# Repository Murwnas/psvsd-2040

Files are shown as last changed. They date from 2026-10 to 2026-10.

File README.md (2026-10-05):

# PSVSD 2040

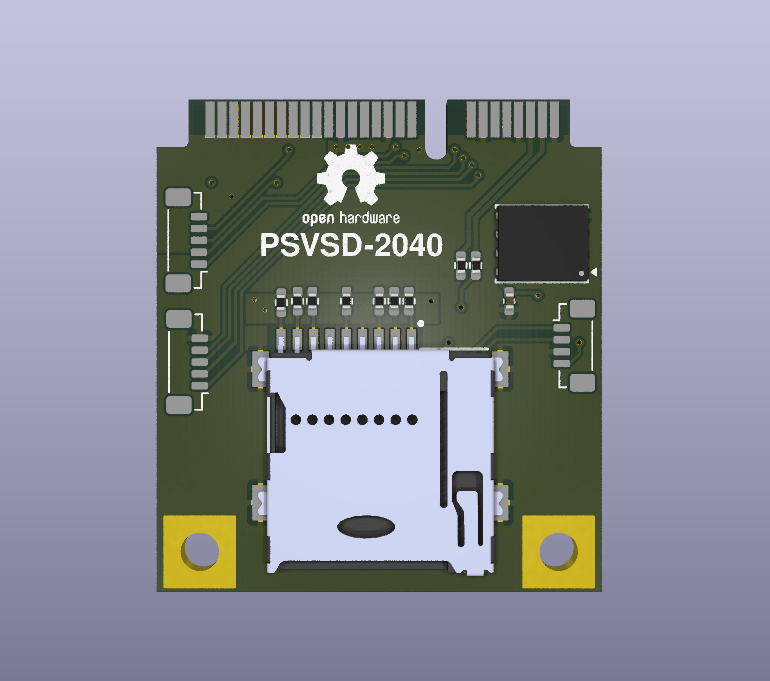
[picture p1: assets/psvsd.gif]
KiCad 3D render


This is a module based on [Yinfanlu's PSVSD adapter](https://github.com/yifanlu/psvsd/). Last year, I took the original Eagle Autodesk files and adapted them to a [KiCad EDA source](https://github.com/Murwnas/psvsd-kicad). This repo code is based on my adaptation. 

One of the problems with the original PSVSD is the out-of-production Genesys chip, which appears to be a generic USB-to-SD bridge that simply exposes Mass Storage. It's theoretically possible to use any such bridge chip in its place, but anyone who has read Yinfanlu's write-up on this will also know that power consumption is the main problem behind those adapters. The PS Vita's modem port never switches off power to the modem port. Therefore, these adapters consume power even when the console is off.

My own fun idea was to recreate this adapter using my favorite chip: The RP2040. It has a USB interface, fast GPIO lines, and very low power consumption---with the potential to go into deep-sleep-like states to draw very small amounts. 

The main downside is USB 1.1 speeds, which theoretically cap at 1.2 MB/s. 

Right now, a board has been designed and fabricated, but I have not had the time to assemble and test it. Whether this is a viable concept will remain to be seen.

Do not attempt to reproduce this unless you are fine with potentially making a faulty board that may or may not fry your PS Vita!

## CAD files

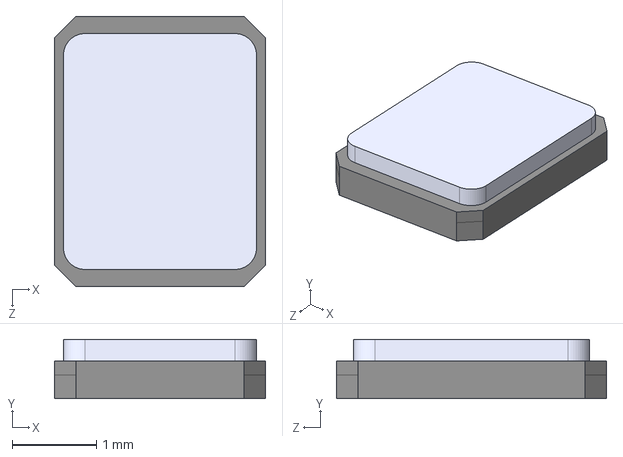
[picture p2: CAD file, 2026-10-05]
assets/step/ABM8-272-T3.STEP
2.50 x 0.7 x 3.20 mm

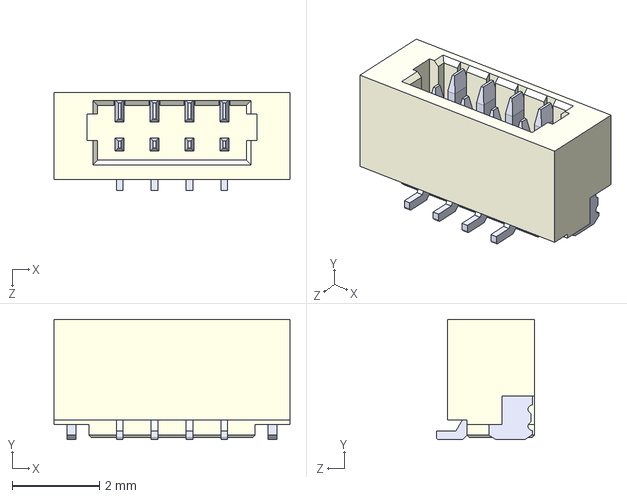
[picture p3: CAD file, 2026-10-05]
assets/step/BM04B-SURS-TF.STEP
5.40 x 2.75 x 2.25 mm

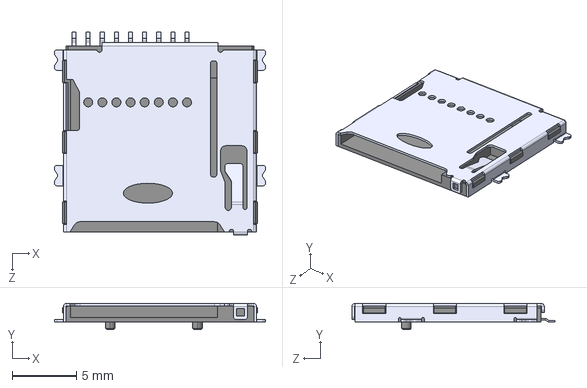
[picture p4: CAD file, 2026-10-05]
assets/step/SD_SLOT.STEP
16.4 x 2.05 x 15.9 mm

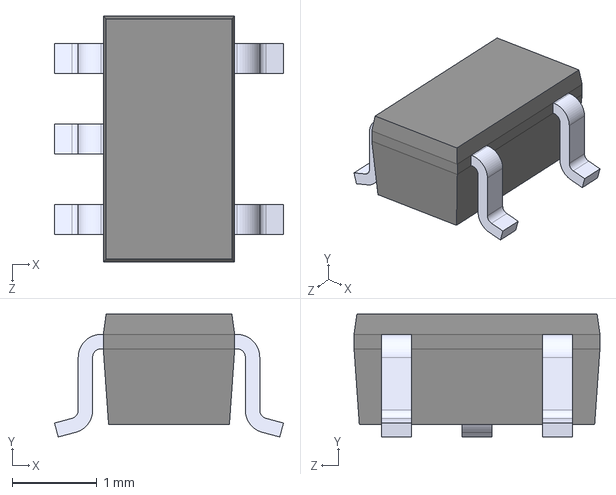
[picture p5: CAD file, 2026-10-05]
assets/step/MIC5504-3.3YM5-TR.step
2.70 x 1.45 x 2.90 mm

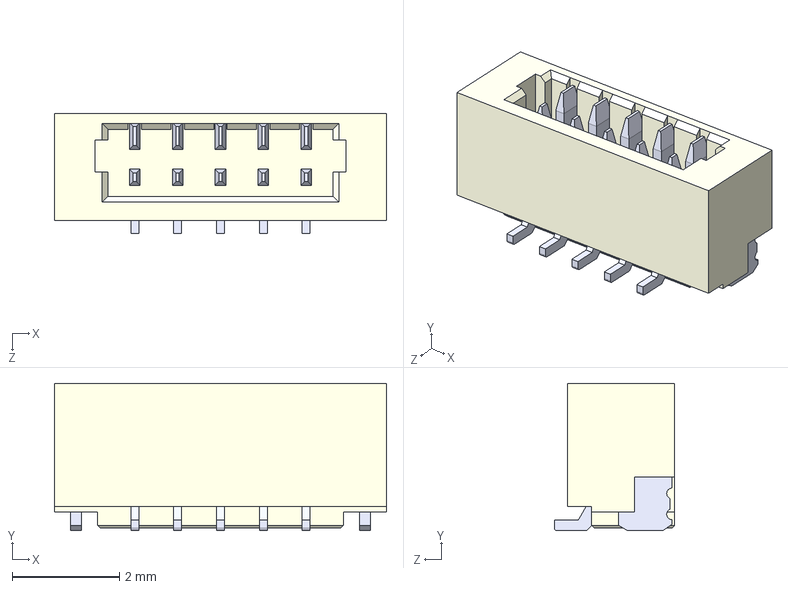
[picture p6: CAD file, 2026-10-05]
assets/step/BM05B-SURS-TF.STEP
6.20 x 2.75 x 2.25 mm

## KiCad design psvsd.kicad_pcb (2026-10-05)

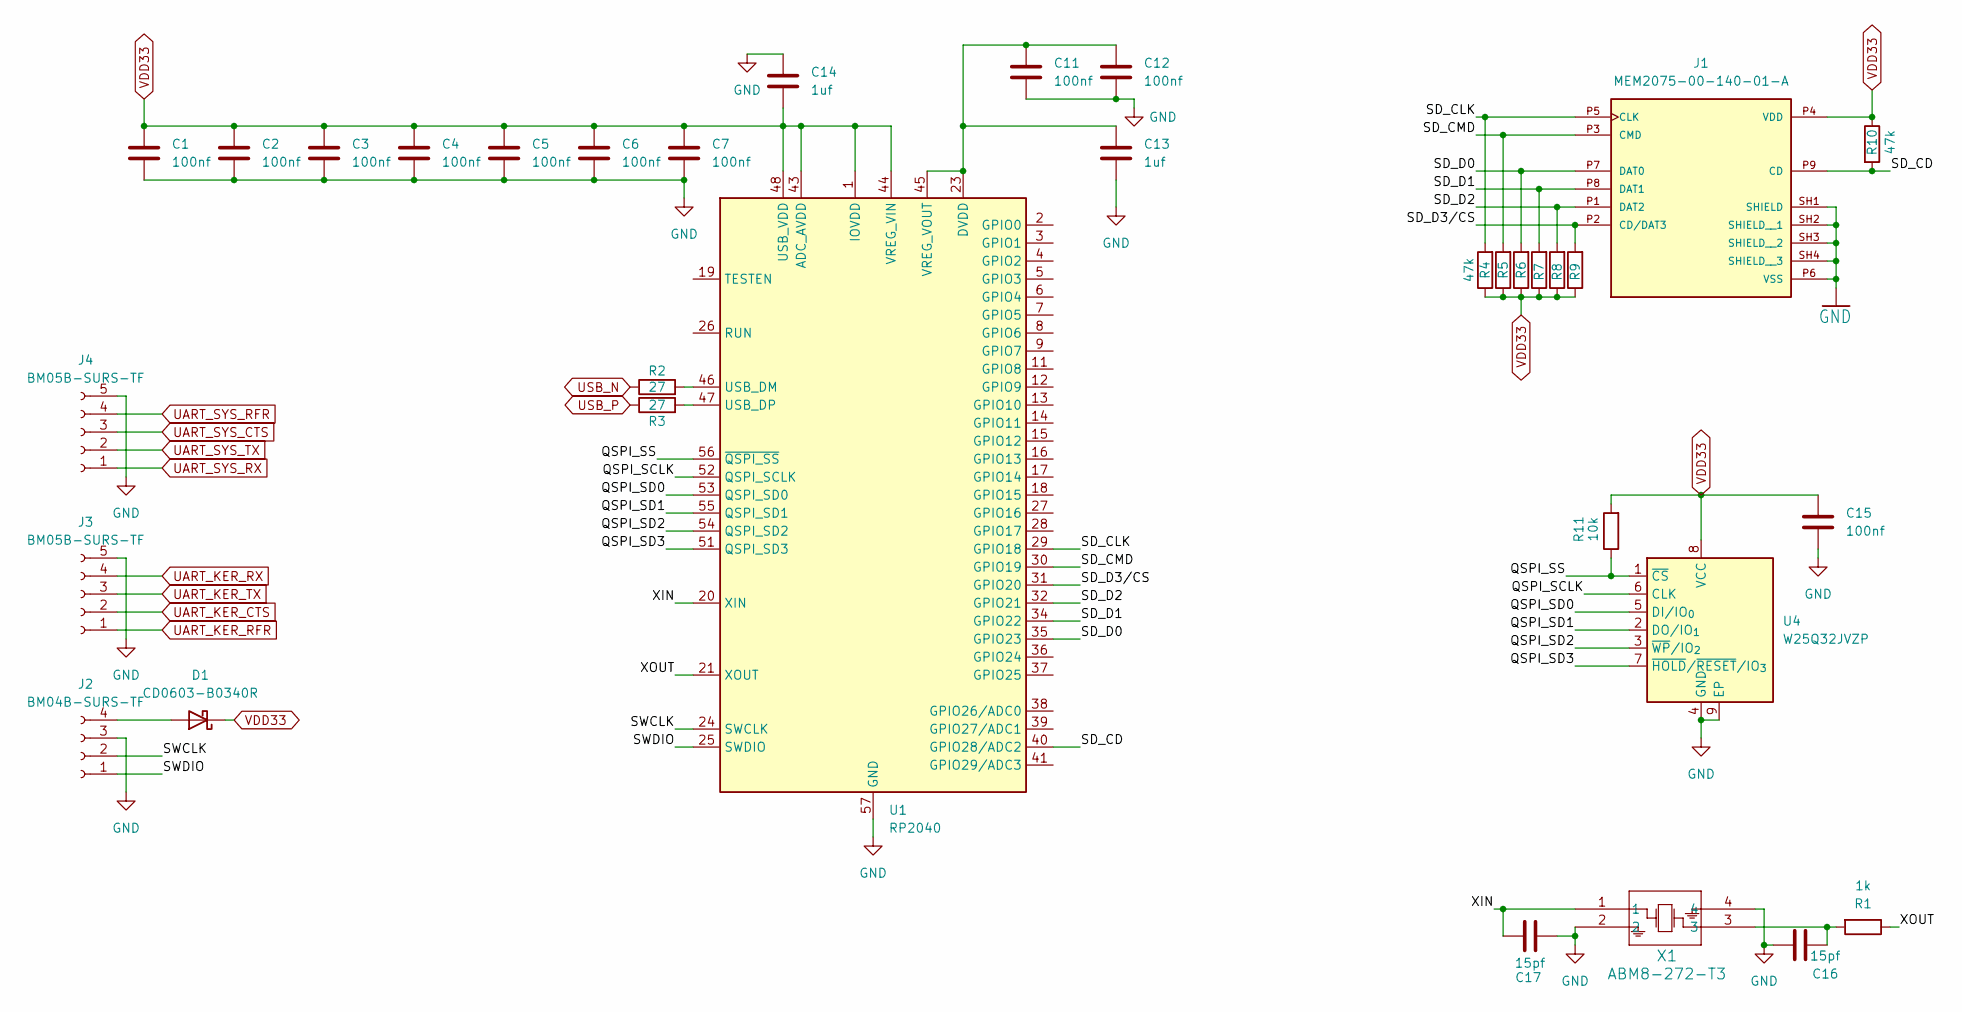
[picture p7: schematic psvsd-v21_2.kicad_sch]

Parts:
C1, C2, C3, C4, C5, C6, C7, C11, C12, C15: 100nf; C_0402_1005Metric_Pad0.74x0.62mm_HandSolder
C13, C14: 1uf; C_0402_1005Metric_Pad0.74x0.62mm_HandSolder
C16, C17: 15pf; C_0402_1005Metric_Pad0.74x0.62mm_HandSolder
D1: CD0603-B0340R; D_0603_1608Metric
J1: MEM2075-00-140-01-A; GCT_MEM2075-00-140-01-A; PARTREV A
J2: BM04B-SURS-TF; JST_SUR_BM04B-SURS-TF_1x04-1MP_P0.80mm_Vertical
J3, J4: BM05B-SURS-TF; JST_SUR_BM05B-SURS-TF_1x05-1MP_P0.80mm_Vertical
R1: 1k; R_0402_1005Metric_Pad0.72x0.64mm_HandSolder
R2, R3: 27; R_0402_1005Metric_Pad0.72x0.64mm_HandSolder
R4, R5, R6, R7, R8, R9, R10: 47k; R_0402_1005Metric_Pad0.72x0.64mm_HandSolder
R11: 10k; R_0402_1005Metric_Pad0.72x0.64mm_HandSolder
U1: RP2040; QFN-56-1EP_7x7mm_P0.4mm_EP3.2x3.2mm
U4: W25Q32JVZP; WSON-8-1EP_6x5mm_P1.27mm_EP3.4x4.3mm
X1: ABM8-272-T3; ABM8-272-T3_ABR

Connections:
/psvsd-2040/QSPI_SCLK: U1.52 (QSPI_SCLK), U4.6 (CLK)
/psvsd-2040/QSPI_SD0: U1.53 (QSPI_SD0), U4.5 (DI/IO_{0})
/psvsd-2040/QSPI_SD1: U1.55 (QSPI_SD1), U4.2 (DO/IO_{1})
/psvsd-2040/QSPI_SD2: U1.54 (QSPI_SD2), U4.3 (~WP/IO_{2})
/psvsd-2040/QSPI_SD3: U1.51 (QSPI_SD3), U4.7 (~HOLD/~RESET/IO_{3})
/psvsd-2040/QSPI_SS: R11.1, U1.56 (~QSPI_SS), U4.1 (~CS)
/psvsd-2040/SD_CD: J1.P9 (CD), R10.2, U1.40 (GPIO28/ADC2)
/psvsd-2040/SD_CLK: J1.P5 (CLK), R4.2, U1.29 (GPIO18)
/psvsd-2040/SD_CMD: J1.P3 (CMD), R5.2, U1.30 (GPIO19)
/psvsd-2040/SD_D0: J1.P7 (DAT0), R6.2, U1.35 (GPIO23)
/psvsd-2040/SD_D1: J1.P8 (DAT1), R7.2, U1.34 (GPIO22)
/psvsd-2040/SD_D2: J1.P1 (DAT2), R8.2, U1.32 (GPIO21)
/psvsd-2040/SD_D3/CS: J1.P2 (CD/DAT3), R9.2, U1.31 (GPIO20)
/psvsd-2040/SWCLK: J2.2, U1.24 (SWCLK)
/psvsd-2040/SWDIO: J2.1, U1.25 (SWDIO)
/psvsd-2040/XIN: C17.2, U1.20 (XIN), X1.1
/psvsd-2040/XOUT: R1.1, U1.21 (XOUT)
GND: C1.2, C2.2, C3.2, C4.2, C5.2, C6.2, C7.2, C11.2, C12.2, C13.2, C14.1, C15.2, C16.1, C17.1, J1.P6 (VSS), J1.SH1 (SHIELD), J1.SH2 (SHIELD__1), J1.SH3 (SHIELD__2), J1.SH4 (SHIELD__3), J2.3, J3.5, J4.5, U1.57 (GND), U4.4 (GND), U4.9 (EP), X1.2, X1.4; also elsewhere on the board
unnamed: C16.2, R1.2, X1.3
unnamed: D1.2 (A), J2.4
unnamed: R2.2, U1.46 (USB_DM)
unnamed: R3.2, U1.47 (USB_DP)
unnamed: C11.1, C12.1, C13.1, U1.23 (DVDD), U1.45 (VREG_VOUT), U1.50 (DVDD)
UART_KER_CTS: J3.2; also elsewhere on the board
UART_KER_RFR: J3.1; also elsewhere on the board
UART_KER_RX: J3.4; also elsewhere on the board
UART_KER_TX: J3.3; also elsewhere on the board
UART_SYS_CTS: J4.3; also elsewhere on the board
UART_SYS_RFR: J4.4; also elsewhere on the board
UART_SYS_RX: J4.1; also elsewhere on the board
UART_SYS_TX: J4.2; also elsewhere on the board
USB_N: R2.1; also elsewhere on the board
USB_P: R3.1; also elsewhere on the board
VDD33: C1.1, C2.1, C3.1, C4.1, C5.1, C6.1, C7.1, C14.2, C15.1, D1.1 (K), J1.P4 (VDD), R4.1, R5.1, R6.1, R7.1, R8.1, R9.1, R10.1, R11.2, U1.1 (IOVDD), U1.10 (IOVDD), U1.22 (IOVDD), U1.33 (IOVDD), U1.42 (IOVDD), U1.43 (ADC_AVDD), U1.44 (VREG_VIN), U1.48 (USB_VDD), U1.49 (IOVDD), U4.8 (VCC); also elsewhere on the board

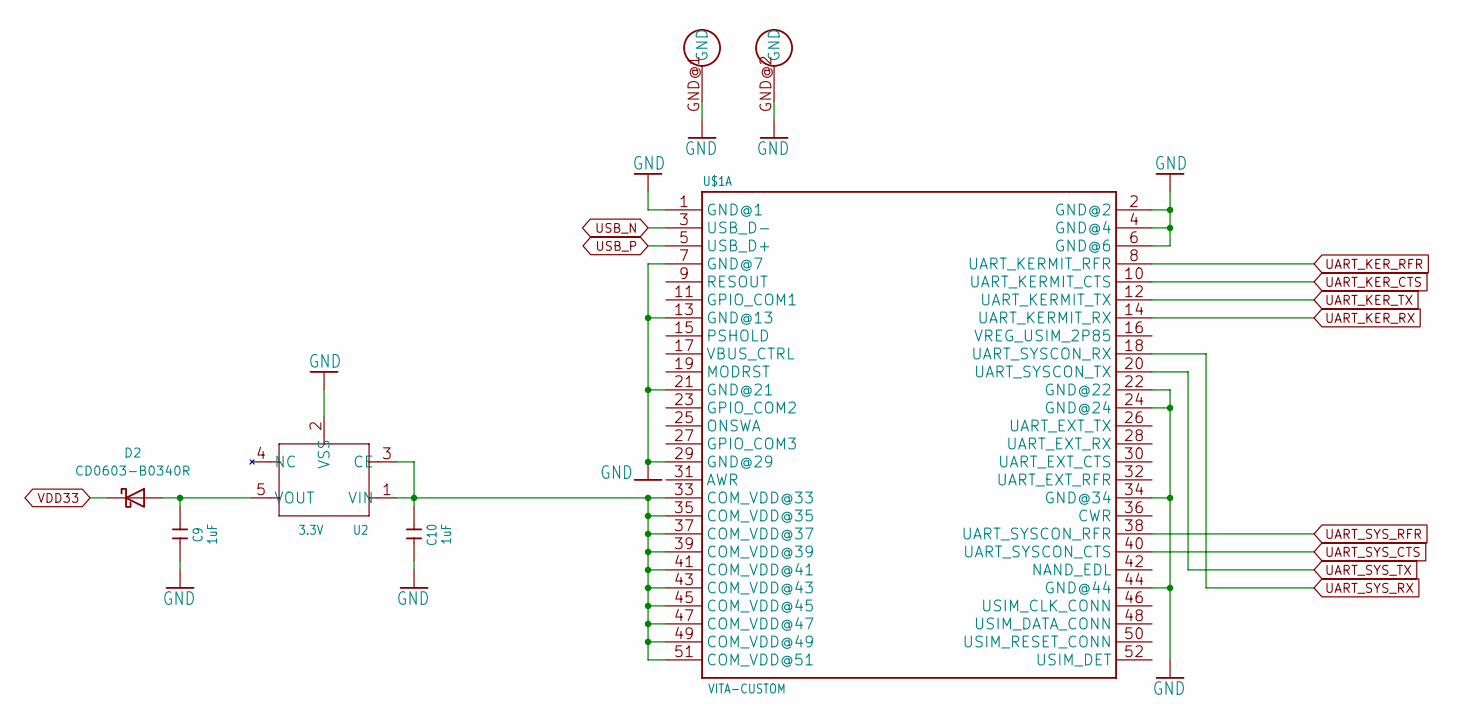
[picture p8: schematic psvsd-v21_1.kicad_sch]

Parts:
C9, C10: 1uF; C_0402_1005Metric_Pad0.74x0.62mm_HandSolder
D2: CD0603-B0340R; D_0603_1608Metric
U2: 3.3V; SOT-23-5_470
U$1: VITA-CUSTOM; VITA-MINI-PCI-E

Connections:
GND: C9.2, C10.2, U2.2 (VSS), U$1.1 (GND@1), U$1.2 (GND@2), U$1.4 (GND@4), U$1.6 (GND@6), U$1.7 (GND@7), U$1.13 (GND@13), U$1.21 (GND@21), U$1.22 (GND@22), U$1.24 (GND@24), U$1.29 (GND@29), U$1.34 (GND@34), U$1.44 (GND@44), U$1.GND@1 (GND), U$1.GND@2 (GND); also elsewhere on the board
unnamed: C9.1, D2.2 (A), U2.5 (VOUT)
unnamed: C10.1, U2.1 (VIN), U2.3 (CE), U$1.33 (COM_VDD@33), U$1.35 (COM_VDD@35), U$1.37 (COM_VDD@37), U$1.39 (COM_VDD@39), U$1.41 (COM_VDD@41), U$1.43 (COM_VDD@43), U$1.45 (COM_VDD@45), U$1.47 (COM_VDD@47), U$1.49 (COM_VDD@49), U$1.51 (COM_VDD@51)
UART_KER_CTS: U$1.10 (UART_KERMIT_CTS); also elsewhere on the board
UART_KER_RFR: U$1.8 (UART_KERMIT_RFR); also elsewhere on the board
UART_KER_RX: U$1.14 (UART_KERMIT_RX); also elsewhere on the board
UART_KER_TX: U$1.12 (UART_KERMIT_TX); also elsewhere on the board
UART_SYS_CTS: U$1.40 (UART_SYSCON_CTS); also elsewhere on the board
UART_SYS_RFR: U$1.38 (UART_SYSCON_RFR); also elsewhere on the board
UART_SYS_RX: U$1.18 (UART_SYSCON_RX); also elsewhere on the board
UART_SYS_TX: U$1.20 (UART_SYSCON_TX); also elsewhere on the board
USB_N: U$1.3 (USB_D-); also elsewhere on the board
USB_P: U$1.5 (USB_D+); also elsewhere on the board
VDD33: D2.1 (K); also elsewhere on the board

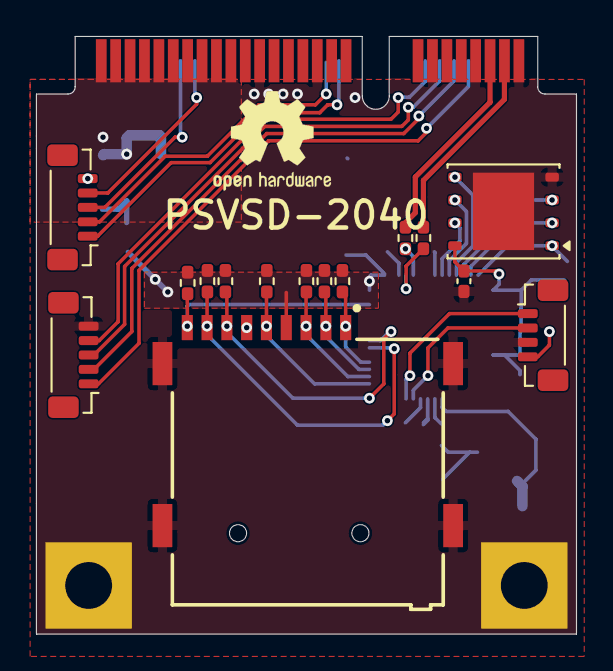
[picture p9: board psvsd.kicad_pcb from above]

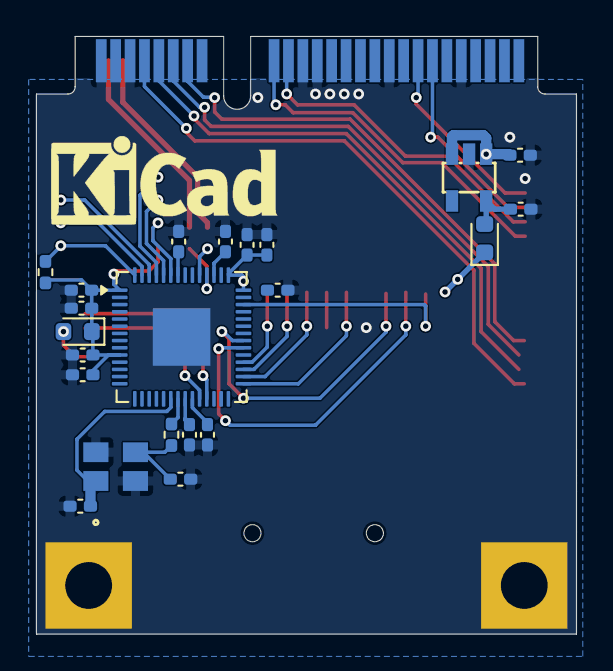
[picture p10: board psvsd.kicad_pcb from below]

Board: 2 copper layers, 30.0 x 33.2 mm, 38 parts (22 on the bottom side), 36 nets.
